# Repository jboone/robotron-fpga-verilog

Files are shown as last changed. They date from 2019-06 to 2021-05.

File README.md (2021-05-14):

# Robotron FPGA (Verilog)

Classic 1980s arcade video game implemented in an FPGA using Verilog, using some [custom video](hw/ecp5_analog_video), [sound](hw/ecp5_dac8), and controls interfacing hardware.

## Status

This project is stable. It has served the [Church of Robotron](https://churchofrobotron.com/) well during the [2019 Crowd Supply Teardown conference](https://www.crowdsupply.com/teardown/portland-2019) and the [2019 Portland Mini Maker Faire](https://omsi.edu/calendar/portland-mini-maker-faire-2019).

## Requirements

* Lattice [LFE5UM5G-85F-EVN FPGA evaluation board](https://www.latticesemi.com/products/developmentboardsandkits/ecp5evaluationboard): This is an economical way to get the largest ECP5 FPGA Lattice makes.
* Williams [Robotron: 2084 ROM binary files](https://duckduckgo.com/?q=robotron+2084+rom&t=hc&va=u&ia=web): These files are often used with MAME, the arcade emulator. CPU board ROM files are named "robotron.sb?", where "?" is "1" through "9" and "a" through "c". The sound board ROM file is named "robotron.snd". You'll also want a "nvram" file containing the desired contents of the game's 1K x 4 nonvolatile RAM.
* [Python](https://www.python.org/) 3.7 or newer: Used to transform ROM and PROM files into HEX files for inclusion in the FPGA bitstream.
* [Yosys](https://github.com/YosysHQ/yosys), [nextpnr](https://github.com/YosysHQ/nextpnr), [prjtrellis](https://github.com/YosysHQ/prjtrellis): Open-source FPGA toolchain required to produce a bitstream for the FPGA. If you don't want to build these from source code, give the [fpga-toolchain](https://github.com/YosysHQ/fpga-toolchain) releases a try. It's important to run recent versions of these tools, as they're advancing rapidly.
* [GHDL](https://github.com/ghdl/ghdl) and [GHDL-Yosys Plugin](https://github.com/ghdl/ghdl-yosys-plugin): These are required to build the [CPU68 6800/6801 VHDL core](rtl/cpu68.vhd), which is the processor in the sound board.
* [OpenOCD](http://openocd.org/): Required to program the development board over a USB cable.

## Notes

Once you have obtained ROM files, you need to put them in the `data/rom` directory. There are `MD5SUMS` and `SHA256SUMS` files in there that you can use to check the hashes for the ROMs you've obtained, to ensure they're the same ones I used. You can do this with either the `md5sum` or `sha256sum` programs, which are commonly pre-installed on UNIX/Linux-based computers:

```bash
$ cd data/rom
$ md5sum -c MD5SUMS
# Should report "OK" for all files listed in the MD5SUMS file.
$ sha256sum -c SHA256SUMS
# Should report "OK" for all files listed in the SHA256SUMS file.
```

To permit OpenOCD to program the ECP5 development board over USB, I had to create a `udev` rule on my Linux computer, as follows:

```bash
$ sudo vi /etc/udev/rules.d/53-lattice-ftdi.rules
# Add this to the file:
ATTRS{idVendor}=="0403", ATTRS{idProduct}=="6010", MODE="0660", GROUP="plugdev", TAG+="uaccess"
# And save and quit the editor.
# Then ask udev to re-read the rules.
$ sudo udevadm control --reload-rules && sudo udevadm trigger
# (Detach and) attach the development board USB cable.
```

With the project requirements installed on your computer, and the development board plugged into your computer, you should only need to do the following to start the game running:

```bash
$ cd robotron-fpga-verilog
$ make prog
```

## Project Hardware

This project includes two custom circuit boards which attach to the Lattice ECP5 development board. Both were made with [KiCAD 5](https://www.kicad.org/). Both are four-layer boards. The bill of materials is contained within the schematic, and can be exported from there. If you're located in North America, consider using the [OSH Park](https://oshpark.com/) four-layer service to fabricate your boards.

### [Analog Video Board](hw/ecp5_analog_video)

The analog video board takes DAC, synchronization, and configuration signals from the ECP5 FPGA and outputs composite video, S-video (separate chroma and luma), and VGA-style RGB.

To use the analog video board, the Lattice ECP5 development board needs a slight configuration change. The FPGA's VCCIO1 voltage supply changed from 2.5V to 3.3V, which involves removing resistor R100 and adding a 0 Ohm resistor as R105. Both resistors are located next to each other, in the very center of the bottom of the board. They appear to be "0603" resistors, which are thankfully manageable to solder for somebody experienced in surface-mount soldering, without fancy tools or a microscope.

### [Analog Audio DAC Board](hw/ecp5_dac8)

The analog audio DAC board takes audio sample data from the ECP5 FPGA and outputs an analog signal.

## Development Board Configuration

Before connecting any of the hardware in this project, please ensure the Lattice ECP5 development board is configured as shown in the following tables.

### Jumpers

| Jumper | State | Function if Installed |
|---|---|---|
| JP1 | Removed | Holds FTDI FT2232H in reset (also stops 12MHz clock output?) |
| JP2 | Installed  | Supplies 12MHz from FTDI FT2232H to FPGA |
| JP3 | Removed | Applies +12V to Arduino header pin J7.8 |
| JP4 | Removed | Applies +5V to Arduino header pin J7.5 |
| JP5 | Removed | Applies +3.3V to Arduino header pin J7.4 |
| JP6 | Removed | Applies +3.3V to Raspberry Pi header pins JP8.1 and JP8.17 |
| JP7 | Removed | Applies +5V to Raspberry Pi header pins JP8.2 and JP8.4 |
| JP9 | Removed | Disables 200MHz LVDS crystal oscillator |
| JP10 | Pins 1,2 | Sets VCCIO0 to +3.3V |
| JP11 | Pins 1,2 | Sets VCCIO7 to +3.3V |
| JP18 | Installed  | Connects 128Mb SPI flash CS# to FPGA CSSPIN |

### DIP Switch SW1

| Switch | Position |
|---|---|
| TP | ON |
| CONFIG 0 | ON |
| CONFIG 1 | OFF |
| CONFIG 2 | ON |

## Interfacing

### Game Controls

The mapping of FPGA pins on the evaluation board can be found in [ecp5evn.lpf](data/ecp5evn.lpf). All signals are active low (0 volts) with the FPGA providing weak pull-ups.

| Game Signal | Evaluation Board Signal | FPGA Ball |
| --- | --- | --- |
| Move Up | Header J5, pin 3 | H20 |
| Move Down | Header J5, pin 11 | K19 |
| Move Left | Header J5, pin 15 | K20 |
| Move Right | Header J5, pin 7 | K18 |
| Fire Up | Header J5, pin 4 | G19 |
| Fire Down | Header J5, pin 12 | J19 |
| Fire Left | Header J5, pin 16 | J20 |
| Fire Right | Header J5, pin 8 | J18 |
| Player Start 1-Up | Header J5, pin 19 | G20 |
| Left Coin Detect  | Push button SW4 | P4 |

Other game signals are set to constant values inside [top.v](rtl/top.v). If you need them, you'll need to do some alteration of the Verilog and .lpf files.

To start a game, you first need to add one or more coins (press push button SW4), then press the player start 1-up button (pulling header J4 pin 19 to ground). And off you go!

### Raspberry Pi Event Reporting

The Lattice ECP5 development board has a [Raspberry Pi](https://www.raspberrypi.org/) [GPIO header](https://www.raspberrypi.org/documentation/usage/gpio/README.md) on it, which we use to send game events to the Raspberry Pi serial port "RX" (GPIO15) signal on header pin 10. The baud rate is approximately 115,200 baud (12 MHz / 104) as determined in [uart_tx.v](rtl/uart_tx.v), and uses eight data bits, one start bit, one stop bit, and no parity. The events are transmitted by [events.v](rtl/events.v), but are detected and captured within [cpu.v](rtl/cpu.v). Have a look at the [simple Python event decoder example](sw/serial-decoder.py) for more details.

## Future Plans

I've gotten hooked on writing my FPGA project hardware descriptions in [nMigen](https://github.com/nmigen/nmigen), so would like to reimplement some or all of the project using nMigen. It should become significantly more concise and less fragile to work with than Verilog code.

## Reference Material

These documents served me well during development of this project.

* [Sean Riddle](http://seanriddle.com/) - Williams arcade machine information, including Robotron: 2084.
    * [Hardware overview](http://seanriddle.com/willhard.html)
    * [Memory map](http://seanriddle.com/memmap.gif)
    * [Processor and video timing](http://seanriddle.com/timing.html)
    * [BLTter description and test code](http://seanriddle.com/blittest.html)
* [Robotron-2084](http://www.robotron-2084.co.uk/) - Williams arcade machine official documentation.
    * [Robotron schematics and instruction manuals](http://www.robotron-2084.co.uk/manualsrobotron.html)
    * [Defender "later series" theory of operation](http://www.robotron-2084.co.uk/manualsdefender.html),
      interesting because the Robotron and Defender hardware is quite
      similar.
* Documentation for various ICs in the original Robotron: 2084 machine.
    * [MC6809E microprocessor datasheet](http://www.classiccmp.org/dunfield/r/6809e.pdf)
    * [MC6809E microprocessor programming manual](http://www.classiccmp.org/dunfield/r/6809prog.pdf)
    * [DM9316 Synchronous 4-Bit Binary Counter](http://www.ti.com/product/dm9316)
    * National Semiconductor(?) DM7489 64-bit random access read/write memory
    (no good reference)
    * [Harris HM-7641 512 x 8 PROM](http://www.bitsavers.org/pdf/harris/_dataBooks/1978_Harris_Memory_Vol1.pdf) (page 2-35)
    * [Harris HM-6514 1024 x 4 CMOS RAM](http://www.bitsavers.org/pdf/harris/_dataBooks/1978_Harris_Memory_Vol1.pdf) (page 3-49)
    * [Mostek MK4116 16,384 x 1 bit dynamic RAM](http://hardware.speccy.org/datasheet/MK4116.pdf)
    * [Signetics 8T97 hex buffer](http://www.bitsavers.org/pdf/signetics/_dataBooks/1977_Bipolar_Microprocessor.pdf) (page 96)
    * [Various 74-series logic ICs](http://www.ti.com/lsds/ti/logic/home_overview.page)

## License

The open-source license for this project is yet to be determined. Stay tuned.

## Contributing

Contributions are welcome!

Please respect Williams Electronics' copyright and do not post any files built with or containing their ROM code.

## Contact

Jared Boone <jared@sharebrained.com>

[ShareBrained Technology, Inc.](http://www.sharebrained.com/)

The latest version of this repository can be found at https://github.com/jboone/robotron-fpga-verilog

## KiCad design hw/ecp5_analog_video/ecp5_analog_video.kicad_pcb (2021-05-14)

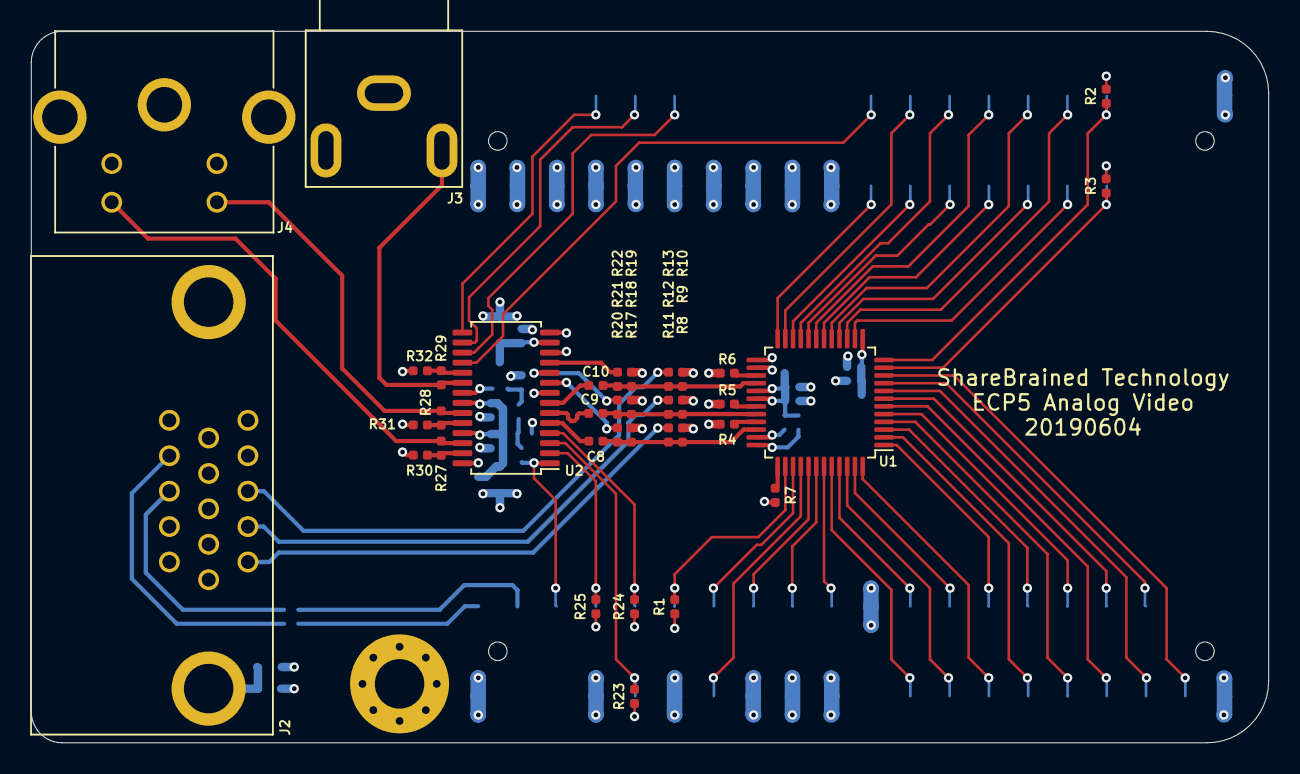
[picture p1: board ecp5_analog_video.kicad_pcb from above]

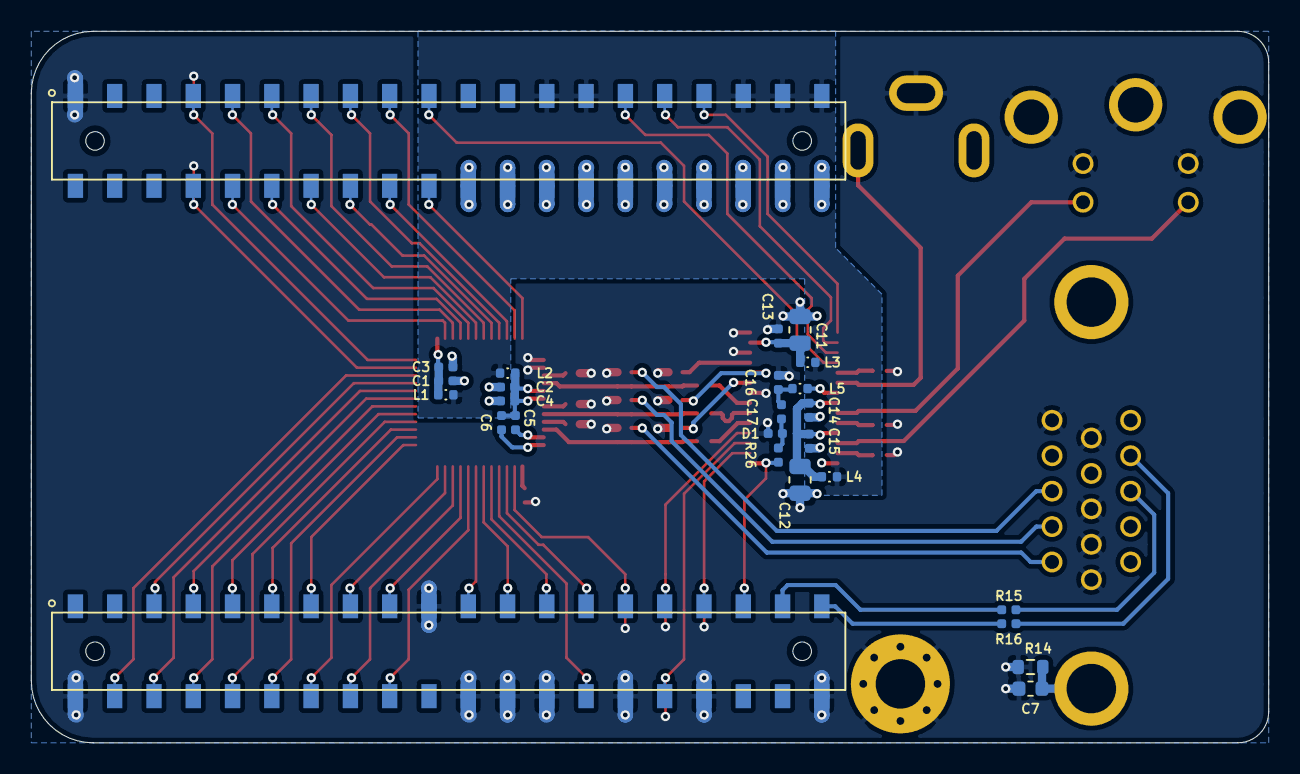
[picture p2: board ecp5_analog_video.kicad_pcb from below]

Board: 4 copper layers, 80.0 x 46.0 mm, 62 parts (25 on the bottom side), 80 nets.

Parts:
C1, C2, C5, C6, C8, C9, C10, C13, C14, C15: 100N; IPC_CAPC100X50X55L25N
C3, C4: 10N; IPC_CAPC100X50X55L25N
C7: 1N; IPC_CAPC160X80X90L35N
C11, C12: 10U; IPC_CAPC200X125X135L45N
C16: 18P; IPC_CAPC100X50X55L25N
C17: 9P; IPC_CAPC100X50X55L25N
D1: 1N4148; IPC_RESC100X50X40L25N
H1: MountingHole_Pad; MountingHole_3.2mm_M3_Pad_Via
J1: ECP5EVB_VERSA
J2: DB15_Female_HighDensity_MountingHoles; ICD15S13E4GX
J3: Barrel_Jack_Switch; PJRAN1X1U__X
J4: Mini-DIN-4; MD-40SMK
L1, L2, L3, L4: L_Small; IPC_INDC100X50X60L20N
L5: 68U; IPC_INDC100X50X60L20N
R1, R2, R3, R23, R24, R25: 100K; IPC_RESC100X50X40L25N
R4, R5, R6, R8, R9, R10, R17, R18, R19, R20, R21, R22: 75R; IPC_RESC100X50X40L25N
R7: 536R; IPC_RESC100X50X40L25N
R11, R12, R13: 0R; IPC_RESC100X50X40L25N
R14: 1M; IPC_RESC160X80X55L25N
R15, R16: 100R; IPC_RESC100X50X40L25N
R26: 47K; IPC_RESC100X50X40L25N
R27, R28, R29: 374R; IPC_RESC100X50X40L25N
R30, R31, R32: 300R; IPC_RESC100X50X40L25N
U1: ADV7123; IPC_QFP48P50_900X900X160L60X22N
U2: AD723; IPC_SOP28P65_970X637X110L60X24N

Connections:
/DAC_B0: J1.J39.10, U1.14
/DAC_B1: J1.J39.09, U1.15
/DAC_B2: J1.J39.12, U1.16
/DAC_B3: J1.J39.11, U1.17
/DAC_B4: J1.J39.14, U1.18
/DAC_B5: J1.J39.13, U1.19
/DAC_B6: J1.J39.16, U1.20
/DAC_B7: J1.J39.15, U1.21
/DAC_B8: J1.J39.18, U1.22
/DAC_B9: J1.J39.17, U1.23
/DAC_BLANK#: J1.J39.08, R3.1, U1.11
/DAC_CLOCK: J1.J39.20, U1.24
/DAC_G0: J1.J40.13, U1.1
/DAC_G1: J1.J40.12, U1.2
/DAC_G2: J1.J40.11, U1.3
/DAC_G3: J1.J40.10, U1.4
/DAC_G4: J1.J40.09, U1.5
/DAC_G5: J1.J40.08, U1.6
/DAC_G6: J1.J40.07, U1.7
/DAC_G7: J1.J40.06, U1.8
/DAC_G8: J1.J40.05, U1.9
/DAC_G9: J1.J40.04, U1.10
/DAC_IOB: C10.2, R10.1, R13.1, R19.1, R22.1, U1.28
/DAC_IOG: C9.2, R9.1, R12.1, R18.1, R21.1, U1.32
/DAC_IOR: C8.2, R8.1, R11.1, R17.1, R20.1, U1.34
/DAC_PSAVE#: J1.J40.29, R1.1, U1.38
/DAC_R0: J1.J40.27, U1.39
/DAC_R1: J1.J40.28, U1.40
/DAC_R2: J1.J40.25, U1.41
/DAC_R3: J1.J40.23, U1.42
/DAC_R4: J1.J40.21, U1.43
/DAC_R5: J1.J40.18, U1.44
/DAC_R6: J1.J40.17, U1.45
/DAC_R7: J1.J40.16, U1.46
/DAC_R8: J1.J40.15, U1.47
/DAC_R9: J1.J40.14, U1.48
/DAC_SYNC#: J1.J39.07, R2.1, U1.12
/ENC_4FSC: J1.J39.29, U2.17
/ENC_CE: J1.J40.32, R23.1, U2.3
/ENC_HSYNC: J1.J39.33, U2.15
/ENC_SA: J1.J40.33, R25.1, U2.2
/ENC_STND: J1.J40.35, R26.1, U2.1
/ENC_TERM: J1.J40.31, R24.1, U2.4
/ENC_TVDET: J1.J39.19, U2.18
/ENC_VSYNC: J1.J39.31, U2.16
/VGA_B: J2.3, R13.2
/VGA_G: J2.2, R12.2
/VGA_HSYNC: J1.J40.37, R15.2
/VGA_R: J2.1, R11.2
/VGA_VSYNC: J1.J40.39, R16.2
GND: C1.1, C2.1, C3.1, C4.1, C7.1, C11.1, C12.1, C13.1, C14.1, C15.1, C16.1, D1.1, H1.1, J1.J39.01, J1.J39.22, J1.J39.24, J1.J39.26, J1.J39.28, J1.J39.30, J1.J39.32, J1.J39.34, J1.J39.36, J1.J39.38, J1.J39.40, J1.J40.02, J1.J40.19, J1.J40.22, J1.J40.24, J1.J40.26, J1.J40.30, J1.J40.34, J1.J40.40, J2.5, J2.6, J2.7, J2.8, J2.10, J3.1, J4.1, J4.2, J4.SH, R1.2, R2.2, R3.2, R4.2, R5.2, R6.2, R7.1, R8.2, R9.2, R10.2, R14.1, R17.2, R18.2, R19.2, R23.2, R24.2, R25.2, R30.2, R31.2, R32.2, U1.25, U1.26, U2.8, U2.12, U2.14, U2.28
unnamed: C1.2, C3.2, L1.2, U1.13
unnamed: C2.2, C4.2, C5.1, C6.1, L2.2, U1.29, U1.30
unnamed: C5.2, U1.35
unnamed: C6.2, U1.36
unnamed: C7.2, J2.0, R14.2
unnamed: C8.1, U2.5
unnamed: C9.1, U2.6
unnamed: C10.1, U2.7
unnamed: C11.2, C13.2, L3.2, U2.13
unnamed: C12.2, C14.2, C15.2, L4.2, U2.22, U2.25
unnamed: C16.2, C17.2, L5.2
unnamed: C17.1, D1.2, R26.2
unnamed: J2.13, R15.1
unnamed: J2.14, R16.1
unnamed: J3.2, R29.1, U2.20
unnamed: J4.3, R27.1, U2.26
unnamed: J4.4, R28.1, U2.23
unnamed: L5.1, U2.21
unnamed: R4.1, U1.33
unnamed: R5.1, U1.31
unnamed: R6.1, U1.27
unnamed: R7.2, U1.37
unnamed: R20.2, U2.9
unnamed: R21.2, U2.10
unnamed: R22.2, U2.11
unnamed: R27.2, R30.1, U2.27
unnamed: R28.2, R31.1, U2.24
unnamed: R29.2, R32.1, U2.19
VAA: J1.J39.25, J1.J39.27, J1.J39.35, J1.J39.37, J1.J39.39, L1.1, L2.1, L3.1, L4.1

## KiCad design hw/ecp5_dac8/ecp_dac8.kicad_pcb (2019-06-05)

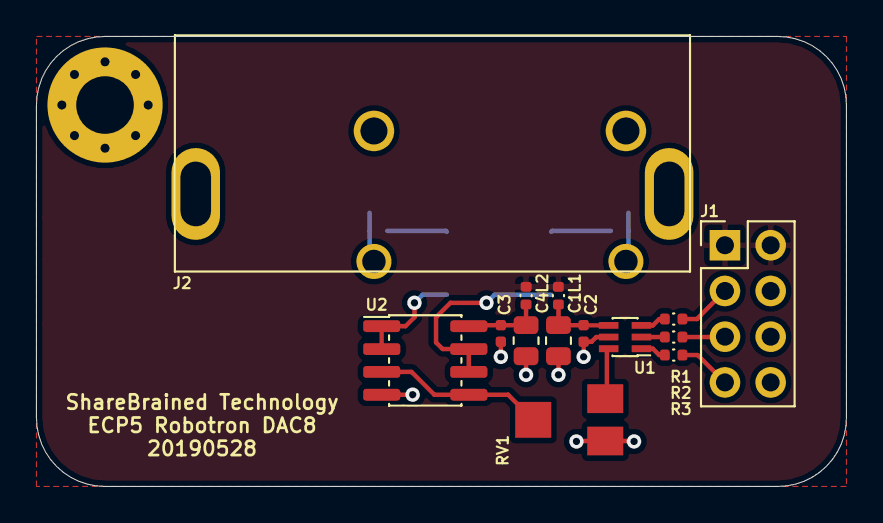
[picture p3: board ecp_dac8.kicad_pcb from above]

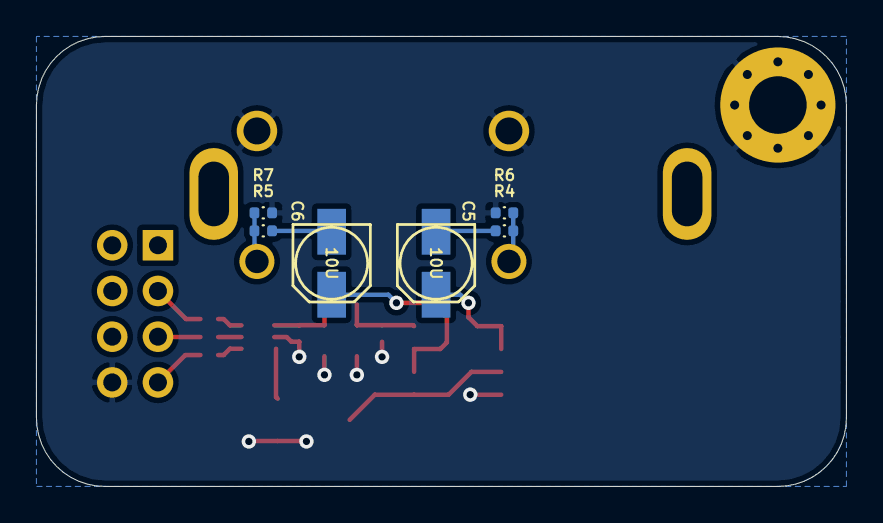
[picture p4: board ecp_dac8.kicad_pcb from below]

Board: 2 copper layers, 45.0 x 25.0 mm, 21 parts (6 on the bottom side), 18 nets.

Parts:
C1, C4: 10U; IPC_CAPC200X125X135L45N
C2, C3: 100N; IPC_CAPC100X50X55L25N
C5, C6: 10U; IPC_CAPAE430X540N
H1: MountingHole_Pad; MountingHole_3.2mm_M3_Pad_Via
J1: Conn_02x04_Odd_Even; PinHeader_2x04_P2.54mm_Vertical
J2: Conn_Coaxial_x2_Isolated; PJRAS2X1S0_X
L1, L2: FB; IPC_INDC100X50X60L20N
R1, R2, R3, R4, R5: 150R; IPC_INDC100X50X60L20N
R6, R7: 100K; IPC_INDC100X50X60L20N
RV1: 10K; NIDEC_ST-4EA
U1: AD5621BKSZ; IPC_SOT23-6P65_210X110L36X22N
U2: LME49721MAX; IPC_SOIC8P127_490X599X175L84X41N

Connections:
/L16: J1.7, R3.1
/L19: J1.3, R1.1
/L20: J1.5, R2.1
/SCLK: R2.2, U1.2
/SDIN: R1.2, U1.3
/SYNC#: R3.2, U1.1
GND: C1.2, C2.2, C3.2, C4.2, H1.1, J1.8, J2.2, J2.4, R6.2, R7.2, RV1.3, U1.5, U2.4
unnamed: C1.1, C2.1, L1.2, U1.4
unnamed: C3.1, C4.1, L2.1, U2.8
unnamed: C5.1, U2.1, U2.2
unnamed: C5.2, R4.2
unnamed: C6.1, U2.6, U2.7
unnamed: C6.2, R5.2
unnamed: J2.1, R5.1, R7.1
unnamed: J2.3, R4.1, R6.1
unnamed: RV1.1, U1.6
unnamed: RV1.2, U2.3, U2.5
VCC: J1.1, J1.2, L1.1, L2.2

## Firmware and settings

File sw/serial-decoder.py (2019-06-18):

#!/usr/bin/env python3

# Copyright 2019 Jared Boone <jared@sharebrained.com>. Open-source license to be determined.

import sys
import struct

import serial

def score_bcd_to_int(bcd_int):
	try:
		return int('%x' % bcd_int)
	except:
		return None

def event_nvram_dump(s):
	data = s.read(7)
	score, initials = struct.unpack('>I3s', data)
	score = score_bcd_to_int(score)
	print('nvram_dump=%s,%s' % (score, initials))

def event_wave_change(s):
	data = s.read(1)
	wave = struct.unpack('>B', data)[0]
	print('wave_change=%d' % wave)

def event_enforcer_spark(s):
	print('enforcer_spark')

def event_score_changed(s):
	data = s.read(4)
	score = struct.unpack('>I', data)[0]
	score = score_bcd_to_int(score)
	print('score_changed=%s' % score)

def event_game_over(s):
	print('game_over')

def event_grunt_killed_by_electrode(s):
	print('grunt_killed_by_electrode')

def event_human_killed(s):
	print('human_killed')

def event_human_saved(s):
	print('human_saved')

def event_still_trying(s):
	print('still_trying')

def event_player_death(s):
	print('player_death')

def event_game_start(s):
	print('game_start')

def event_boot(s):
	print('boot')

handler_map = {
	0xfb: event_nvram_dump,
	0xfa: event_wave_change,
	0xf9: event_enforcer_spark,
	0xf8: event_score_changed,
	0xf7: event_game_over,
	0xf6: event_grunt_killed_by_electrode,
	0xf5: event_human_killed,
	0xf4: event_human_saved,
	0xf3: event_still_trying,
	0xf2: event_player_death,
	0xf1: event_game_start,
	0xf0: event_boot,
}

s = serial.Serial(sys.argv[1], 115200)

while True:
	c = s.read(1)[0]
	print('%02x' % c)

	if c in handler_map:
		handler_map[c](s)

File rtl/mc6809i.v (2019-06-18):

`timescale 1ns / 1ns
//////////////////////////////////////////////////////////////////////////////////
// Company: 
// Engineer: Greg Miller
// Copyright (c) 2016, Greg Miller
// 
// Create Date:    14:26:59 08/13/2016 
// Design Name: 
// Module Name:    mc6809 
// Project Name:   Cycle-Accurate 6809 Core 
// Target Devices: 
// Tool versions: 
// Description: 
//
// Dependencies: Intended to be standalone Vanilla Verilog.
//
// Revision: 
// Revision 1.0 - Initial Release
// Additional Comments: 
//
//////////////////////////////////////////////////////////////////////////////////


//
// The 6809 has incomplete instruction decoding.  A collection of instructions, if met, end up actually behaving like
// a binary-adjacent neighbor.  
//
// The soft core permits three different behaviors for this situation, controlled by the instantiation parameter
// ILLEGAL_INSTRUCTIONS
//
// "GHOST" - Mimic the 6809's incomplete decoding.  This is as similar to a hard 6809 as is practical.  [DEFAULT]
//
// "STOP"  - Cause the soft core to cease execution, placing $DEAD on the address bus and R/W to 'read'.  Interrupts,
//           bus control (/HALT, /DMABREQ), etc. are ignored.  The core intentionally seizes in this instance.  
//           (Frankly, this is useful when making changes to the core and you have a logic analyzer connected.)
//
// "IGNORE"- Cause the soft core to merely ignore illegal instructions.  It will consider them 1-byte instructions and
//           attempt to fetch and run an exception 1 byte later.
//

module mc6809i
#(
    parameter ILLEGAL_INSTRUCTIONS="GHOST"
) 
(
    input  wire [  7:0] D,
    output wire [  7:0] DOut,
    output wire [ 15:0] ADDR,
    output wire         RnW,
    input  wire         E,
    input  wire         Q,
    output wire         BS,
    output wire         BA,
    input  wire         nIRQ,
    input  wire         nFIRQ,
    input  wire         nNMI,
    output wire         AVMA,
    output wire         BUSY,
    output wire         LIC,
    input  wire         nHALT,
    input  wire         nRESET,
    input  wire         nDMABREQ,
    output wire [111:0] RegData,
    output reg          new_opcode
);

reg     [7:0]  DOutput;

assign DOut = DOutput;

reg     RnWOut;         // Combinatorial     

reg     rLIC;
assign LIC = rLIC;

reg     rAVMA;
assign AVMA = rAVMA;

reg     rBUSY;
assign BUSY = rBUSY;

// Bus control
// BS    BA
//  0     0   normal (CPU running, CPU is master)
//  0     1   Interrupt Ack
//  1     0   Sync Ack
//  1     1   CPU has gone high-Z on A, D, R/W
//

assign RnW = RnWOut;


/////////////////////////////////////////////////
// Vectors
`define RESET_VECTOR        16'HFFFE
`define NMI_VECTOR          16'HFFFC
`define SWI_VECTOR          16'HFFFA
`define IRQ_VECTOR          16'HFFF8
`define FIRQ_VECTOR         16'HFFF6
`define SWI2_VECTOR         16'HFFF4
`define SWI3_VECTOR         16'HFFF2
`define Reserved_VECTOR     16'HFFF0

//////////////////////////////////////////////////////
// Latched registers
//

// The last-latched copy.
reg     [7:0]           a;
reg     [7:0]           b;
reg     [15:0]          x;
reg     [15:0]          y;
reg     [15:0]          u;
reg     [15:0]          s;
reg     [15:0]          pc;
reg     [7:0]           dp;
reg     [7:0]           cc;
reg     [15:0]          tmp;
reg     [15:0]          addr;
reg     [15:0]          ea;


// Debug ability to export register contents
assign  RegData[7:0] = a;
assign  RegData[15:8] = b;
assign  RegData[31:16] = x;
assign  RegData[47:32] = y;
assign  RegData[63:48] = s;
assign  RegData[79:64] = u;
assign  RegData[87:80] = cc;
assign  RegData[95:88] = dp;
assign  RegData[111:96] = pc;



// The values as being calculated
reg     [7:0]           a_nxt;
reg     [7:0]           b_nxt;
reg     [15:0]          x_nxt;
reg     [15:0]          y_nxt;
reg     [15:0]          u_nxt;
reg     [15:0]          s_nxt;
reg     [15:0]          pc_nxt;
reg     [7:0]           dp_nxt;
reg     [7:0]           cc_nxt;
reg     [15:0]          addr_nxt;
reg     [15:0]          ea_nxt;
reg     [15:0]          tmp_nxt;

reg                     BS_nxt;
reg                     BA_nxt;

// for ADDR, BS/BA, assign them to the flops
assign BS = BS_nxt;
assign BA = BA_nxt;
assign ADDR=addr_nxt;

localparam CC_E=  8'H80;
localparam CC_F=  8'H40;
localparam CC_H=  8'H20;
localparam CC_I=  8'H10;
localparam CC_N=  8'H08;
localparam CC_Z=  8'H04;
localparam CC_V=  8'H02;
localparam CC_C=  8'H01;

localparam CC_E_BIT=  3'd7;
localparam CC_F_BIT=  3'd6;
localparam CC_H_BIT=  3'd5;
localparam CC_I_BIT=  3'd4;
localparam CC_N_BIT=  3'd3;
localparam CC_Z_BIT=  3'd2;
localparam CC_V_BIT=  3'd1;
localparam CC_C_BIT=  3'd0;

// Convenience calculations
reg     [15:0] pc_p1;
reg     [15:0] pc_p2;
reg     [15:0] pc_p3;
reg     [15:0] s_p1;
reg     [15:0] s_m1;
reg     [15:0] u_p1;
reg     [15:0] u_m1;
reg     [15:0] addr_p1;
reg     [15:0] ea_p1;

//////////////////////////////////////////////////////
// NMI Mask
//
// NMI is supposed to be masked - despite the name - until the 6809 loads a value into S.
// Frankly, I'm cheating slightly.  If someone does a LDS #$0, it won't disable the mask.  Pretty much anything else 
// that changes the value of S from the default (which is currently $0) will clear the mask.  A reset will set the mask again.
reg     NMIMask;

reg     NMILatched;
reg     NMISample;
reg     NMISample2;
reg     NMIClear;
reg     NMIClear_nxt;
wire    wNMIClear = NMIClear;

reg     IRQLatched;

reg     IRQSample;
reg     IRQSample2;
reg     FIRQLatched;
reg     FIRQSample;
reg     FIRQSample2;
reg     HALTLatched;
reg     HALTSample;
reg     HALTSample2;
reg     DMABREQLatched;
reg     DMABREQSample;
reg     DMABREQSample2;

// Interrupt types
localparam INTTYPE_NMI      = 3'H0 ;
localparam INTTYPE_IRQ      = 3'H1 ;
localparam INTTYPE_FIRQ     = 3'H2 ;
localparam INTTYPE_SWI      = 3'H3 ;
localparam INTTYPE_SWI2     = 3'H4 ;
localparam INTTYPE_SWI3     = 3'H5 ;

reg [2:0] IntType;
reg [2:0] IntType_nxt;

//////////////////////////////////////////////////////
// Instruction Fetch Details
//
reg     InstPage2;
reg     InstPage3;
reg     InstPage2_nxt;
reg     InstPage3_nxt;

reg     [7:0]        Inst1;
reg     [7:0]        Inst2;
reg     [7:0]        Inst3;
reg     [7:0]        Inst1_nxt;
reg     [7:0]        Inst2_nxt;
reg     [7:0]        Inst3_nxt;


localparam CPUSTATE_RESET      =  7'd0;
localparam CPUSTATE_RESET0     =  7'd1;

localparam CPUSTATE_RESET2     =  7'd3;
localparam CPUSTATE_FETCH_I1   =  7'd4;
localparam CPUSTATE_FETCH_I1V2 =  7'd5;     
localparam CPUSTATE_FETCH_I2   =  7'd8;

localparam CPUSTATE_LBRA_OFFSETLOW =  7'd17;
localparam CPUSTATE_LBRA_DONTCARE  =  7'd18;
localparam CPUSTATE_LBRA_DONTCARE2 =  7'd19;



localparam CPUSTATE_BRA_DONTCARE   =  7'd20;

localparam CPUSTATE_BSR_DONTCARE1  =  7'd21;
localparam CPUSTATE_BSR_DONTCARE2  =  7'd22;
localparam CPUSTATE_BSR_RETURNLOW  =  7'd23;
localparam CPUSTATE_BSR_RETURNHIGH =  7'd24;
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

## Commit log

2019-06-05 Initial commit of actual stuff.
    [ecp5_analog_video.kicad_pcb, ecp5_analog_video.sch, ecp_dac8.kicad_pcb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]
2019-06-18 Change some signals to 3.3V VCCIO, renumber DIP switches.
2019-06-18 Rename button signal disable button and 12MHz clock internal pull-ups.
2019-06-18 Take one Raspberry Pi GPIO pin for events TX.
2019-06-18 Declare signals on J5 as joystick move/fire inputs and player 1 start button.
2019-06-18 Add Diamond delcaration of SPI programming passthrough.
2019-06-18 CPU: Minor initialization cut-and-paste oops.
2019-06-18 Testbench: Events to UART output.
2019-06-18 Sample Python serial events dispatcher.
2019-07-15 6800: Extend some instructions to match cycle count in data sheet.
    This makes the pitch of sound effects much closer to the original game.
2019-07-15 Sound: Expose diagnostic signal, a few syntax tweaks.
    Diagnostic is available on original hardware as a push button that asserts NMI# and produces a sequence of test sounds.
2019-07-15 Boards: Update component values and part numbers.
    [ecp5_analog_video.sch, ecp_dac8.sch]
2019-07-15 DAC8 PCB: Correct package category for some resistors.
    [ecp_dac8.sch]
2019-07-15 Video PCB: Note about ECP5 initial I/O state.
    [ecp5_analog_video.sch]
2021-05-14 Added details about the video and audio board designs.
2021-05-14 Analog video board: update some resistor values.
    [ecp5_analog_video.kicad_pcb]
2021-05-14 Lots more README documentation
    Links to the hardware (circuit boards) portion of the project.
    Instructions on how to build and load the bitstream on the development board.
    Game control pinout.
    Raspberry Pi interface info.
    Future project plans.
    Clean up bullet-points formatting.
    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
